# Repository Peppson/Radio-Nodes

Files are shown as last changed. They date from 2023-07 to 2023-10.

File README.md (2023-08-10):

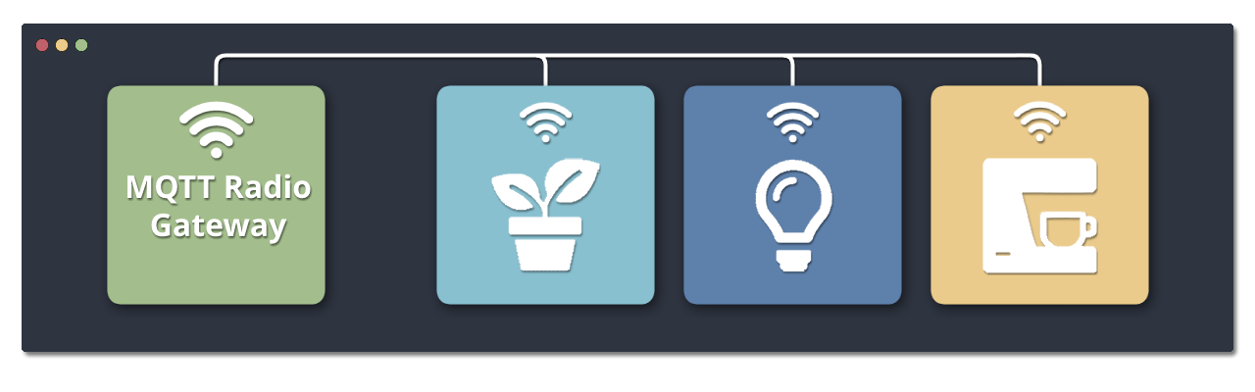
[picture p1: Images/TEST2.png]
flow diagram


# loading...

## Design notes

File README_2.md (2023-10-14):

flow_diagram

<div align="center">
    <h1>
        Radio Nodes         
        <a href="https://www.gnu.org/licenses/gpl-3.0"> 
            
        </a>     
    </h1>   
</div>

Solar/USB/Battery powered NRF24L01+ transceiver modules,  based on the Attiny84 microcontroller.  
Serves as the end-Node of [MQTT-Radio-Gateway](https://github.com/Peppson/MQTT-Radio-Gateway).     
Written in C++ with Arduino/PlatformIO framework.

&nbsp; 
## Project Overview
- Primarily made for personal "needs" and as a learning experience.   
  However if there's anything here that can benefit someone else's project,   
  feel free to use it!
- Easily configurable for different jobs, such as moving servos, starting pumps etc.
- Most configuration can be found in `include/config.h`.
- The `helpers` folder includes a few .ino files for calibration/setup etc.

&nbsp; 
## Hardware - PCB for Attiny84 MCU
Designed a custom PCB to fit all components more easily,  in a compact format.   
Kicad files can be found here: 
[📂 kicad - radio nodes/](./.kicad%20-%20ESP32%20shield)  
More project images in: 
[📂 images/](./images/)  

&nbsp;
Kicad PCB img   

### Finished hardware:
Finished hardware   

&nbsp; 
## Nodes

<details>
    <summary>
        Nodes 1-5: Solar-powered self watering plants
    </summary>

Uses a 3-5V waterpump and DIY capacative fluid-level sensor.  
[Liquid Level Sensing Using Capacitive-to-Digital Converters](https://www.analog.com/en/analog-dialogue/articles/liquid-level-sensing-using-cdcs.html)
<br>   
</details>

<details>
    <summary>
        Nodes 6-10: USB-powered self watering plants
    </summary>
    Same as above but skips the TP4056 charging board and battery.   

<br> 
</details>

<details>
    <summary>
        Node 11: Mocca Master controller 
    </summary>
    Uses a simple SG90 servo and a hall-effect current sensor.     
<br>
</details>

## License 
See the [LICENSE](./LICENSE) file for more information.  
&nbsp;

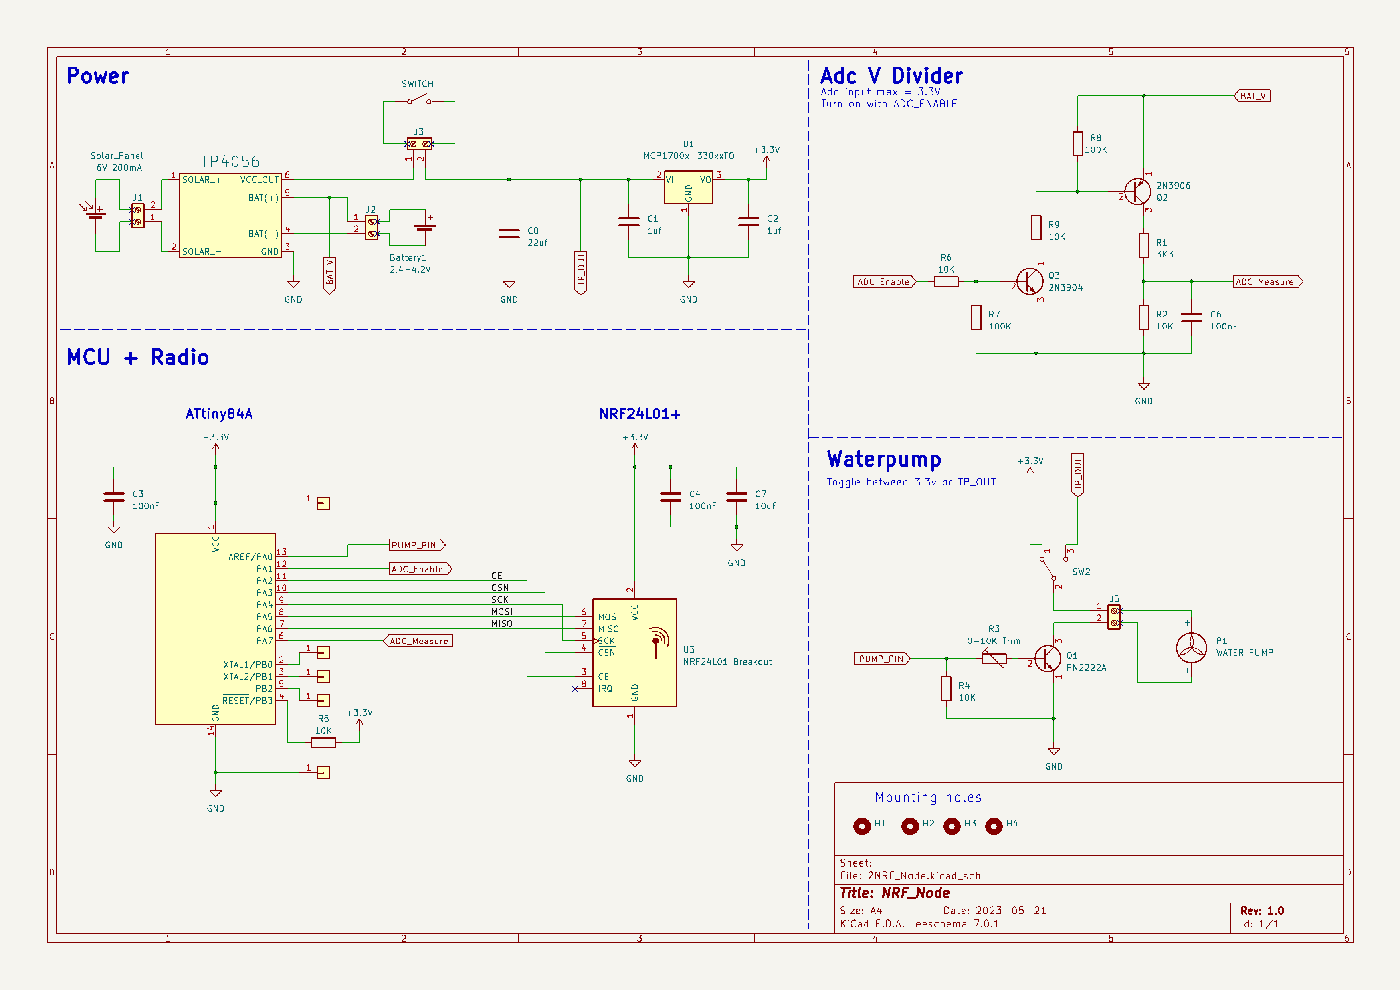
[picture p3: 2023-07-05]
Images/Kicad schematic.png

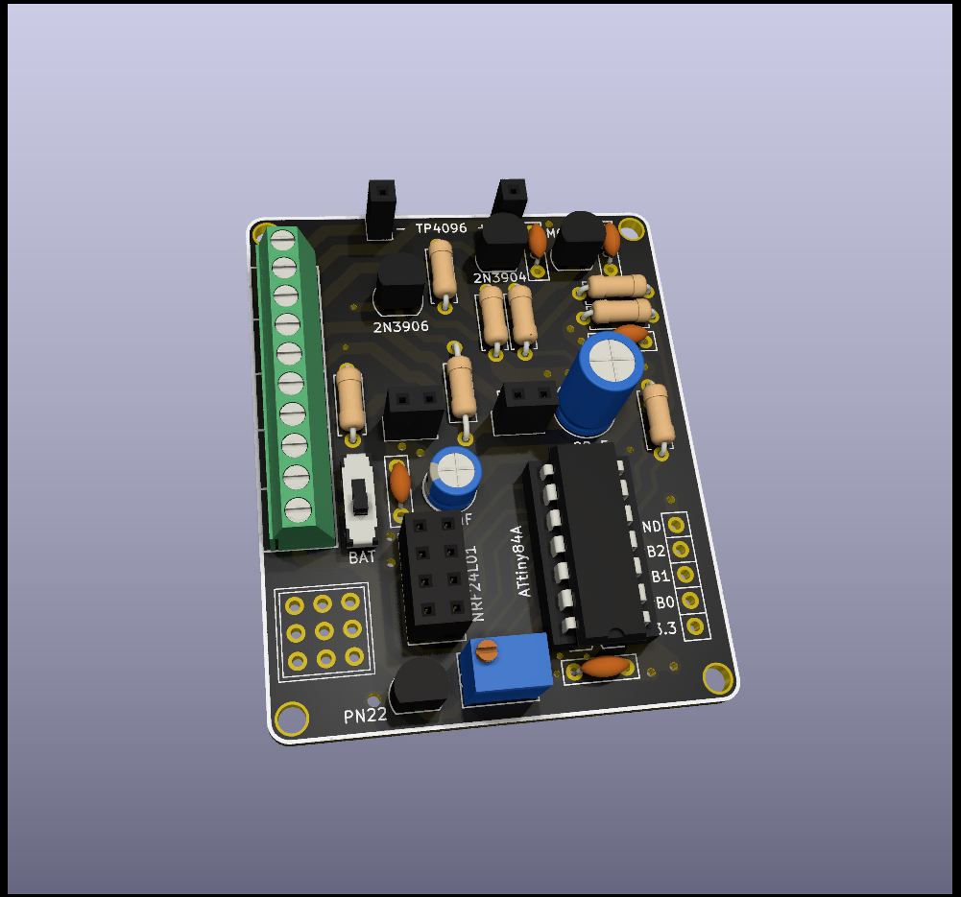
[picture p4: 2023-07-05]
Images/Node pcb.png

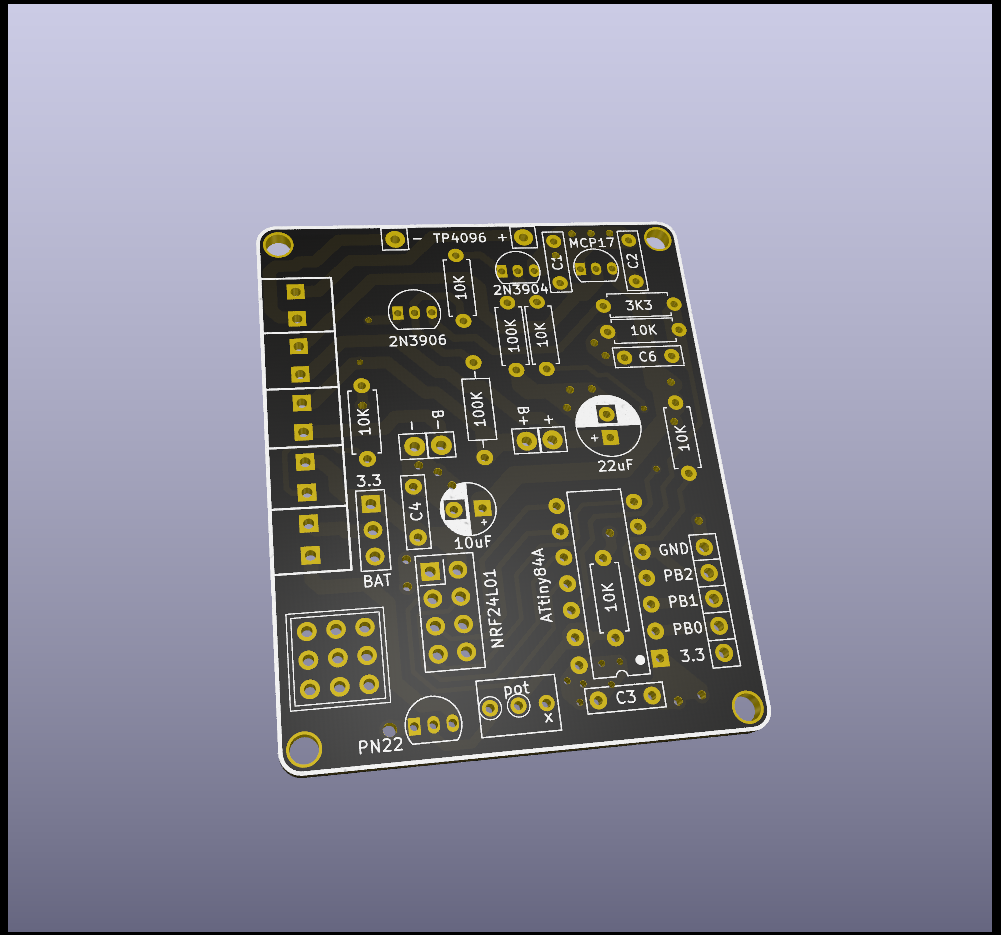
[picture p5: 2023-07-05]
Images/Node pcb naked.png

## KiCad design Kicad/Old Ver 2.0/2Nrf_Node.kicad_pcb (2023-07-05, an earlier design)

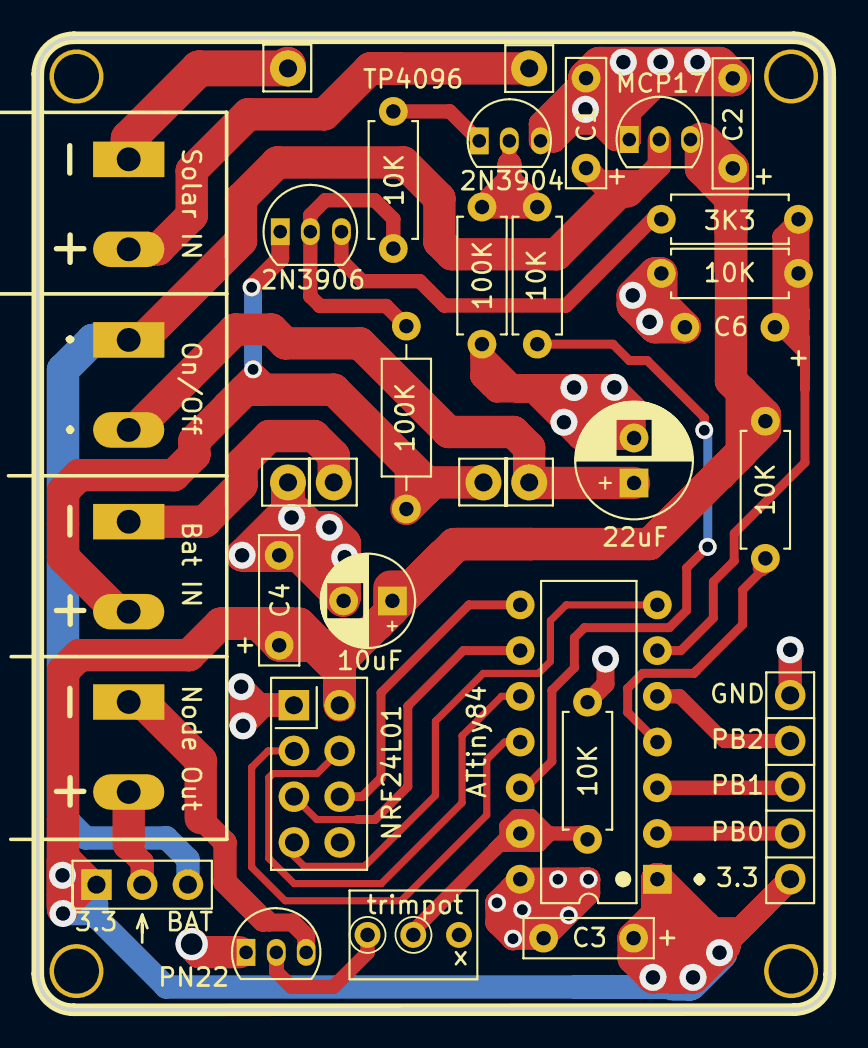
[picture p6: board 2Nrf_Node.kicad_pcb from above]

Board: 2 copper layers, 44.0 x 54.0 mm, 32 parts (0 on the bottom side), 26 nets.

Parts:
10K: 10K; R_Axial_DIN0207_L6.3mm_D2.5mm_P7.62mm_Horizontal
C1, C2: 1uf; C_Rect_L7.0mm_W2.0mm_P5.00mm
C3, C4, C6: 100nF; C_Rect_L7.0mm_W2.0mm_P5.00mm
C5: 22uF; CP_Radial_D6.3mm_P2.50mm
C7: 10uF; CP_Radial_D5.0mm_P2.50mm
H1, H2, H4, H4#2: MountingHole; TestPoint_Keystone_5010-5014_Multipurpose
J1, J2, J3, J4: Terminal Block; TerminalBlock_Altech_AK300-2_P5.00mm
Pins: PinHeader_1x03_P2.54mm_Vertical
Q1: PN2222A; TO-92_Inline
Q2: 2N3906; TO-92_Inline
Q3: 2N3904; TO-92_Inline
R1: 3K3; R_Axial_DIN0207_L6.3mm_D2.5mm_P7.62mm_Horizontal
R2, R3, R6, R9: 10K; R_Axial_DIN0207_L6.3mm_D2.5mm_P7.62mm_Horizontal
R7: 100K; R_Axial_DIN0207_L6.3mm_D2.5mm_P7.62mm_Horizontal
R8: 100K; R_Axial_DIN0207_L6.3mm_D2.5mm_P10.16mm_Horizontal
SW2: SW_SPDT; PinHeader_1x03_P2.54mm_Vertical
TP4056: TP4056-Module
U1: MCP1700x-330xxTO; TO-92_Inline
U2: ATtiny84A-P; DIP-14_W7.62mm
U3: NRF24L01_Breakout; nRF24L01_Breakout

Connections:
1234: Q3.1 (E), R9.2
+3.3V: 10K.2, C2.1, C3.1, C4.1, C7.1, Pins.5, SW2.1 (A), U1.3 (VO), U2.1 (VCC), U3.2 (VCC)
/CE: U2.11 (PA2), U3.3 (CE)
/CSN: U2.10 (PA3), U3.4 (~CSN)
/MISO: U2.7 (PA6), U3.7 (MISO)
/MOSI: U2.8 (PA5), U3.6 (MOSI)
/SCK: U2.9 (PA4), U3.5 (SCK)
ADC_Enable: R6.1, U2.12 (PA1)
ADC_Measure: C6.1, R1.2, R2.1, U2.6 (PA7)
BAT_-: J3.1, TP4056.6 (VCC_OUT)
BAT_V: Q2.1 (E), R8.1, TP4056.5 (BAT(+))
GND: C1.2, C2.2, C3.2, C4.2, C5.2, C6.2, C7.2, Pins.1, Q1.1 (E), Q3.3 (C), R2.2, R3.1, R7.2, TP4056.4 (BAT(-)), U1.1 (GND), U2.14 (GND), U3.1 (GND)
unnamed: J4.2, SW2.2 (B)
unnamed: J4.1, Q1.3 (C)
unnamed: Pins.2, U2.5 (PB2)
unnamed: Pins.4, U2.2 (XTAL1/PB0)
unnamed: Pins.3, U2.3 (XTAL2/PB1)
unnamed: R3.2, U2.13 (AREF/PA0)
unnamed: Q2.2 (B), R8.2, R9.1
unnamed: Q2.3 (C), R1.1
unnamed: Q3.2 (B), R6.2, R7.1
unnamed: 10K.1, U2.4 (~RESET/PB3)
tp_+: J1.2, TP4056.1 (VCC_IN)
tp_-: J1.1, TP4056.2 (GND)
tp_out_+: C5.1, J2.2, TP4056.3 (GND)
tp_out_++: C1.1, J2.1, SW2.3 (C), U1.2 (VI)

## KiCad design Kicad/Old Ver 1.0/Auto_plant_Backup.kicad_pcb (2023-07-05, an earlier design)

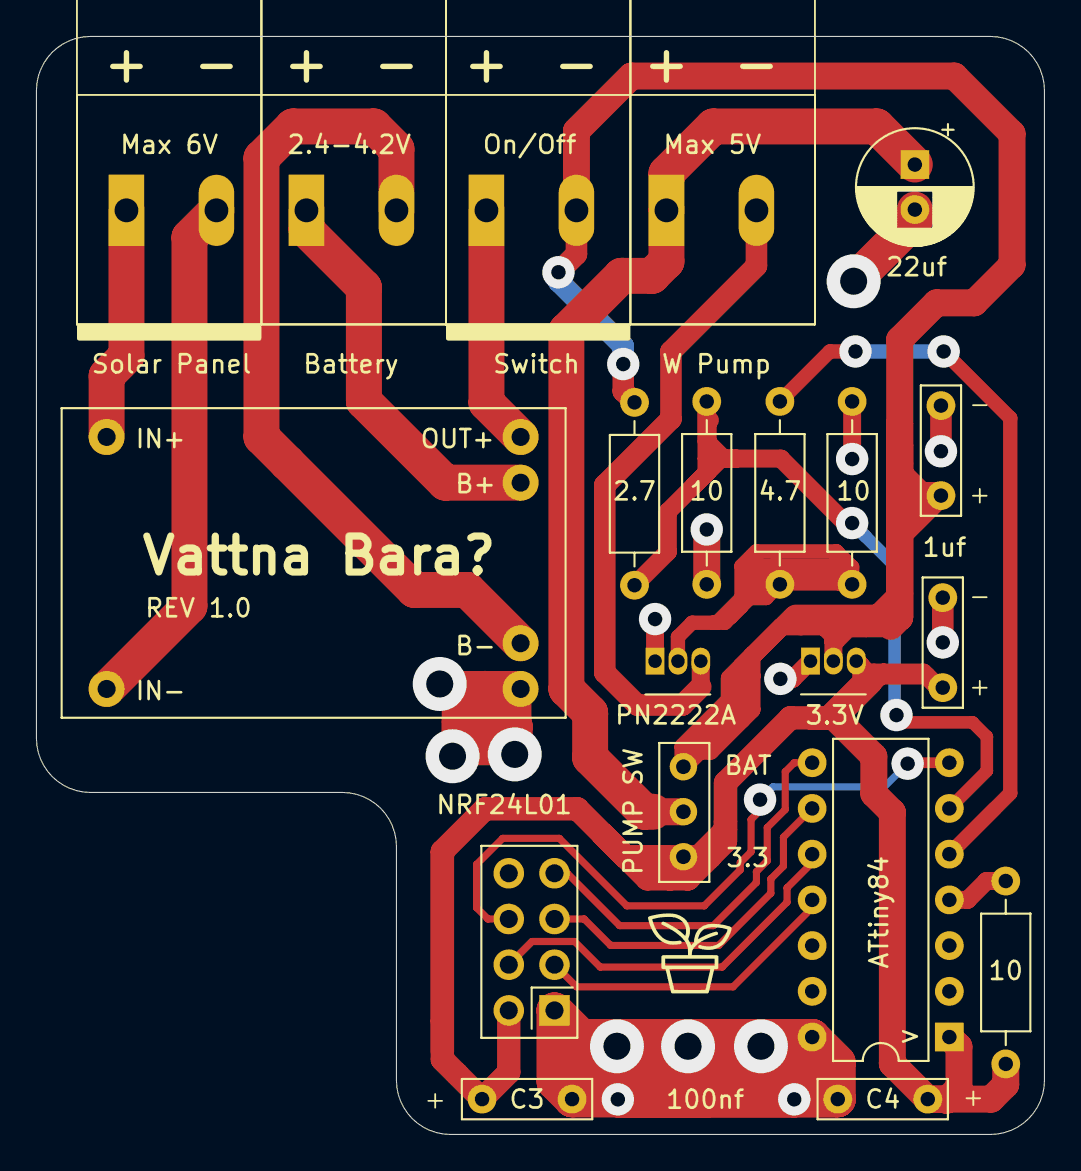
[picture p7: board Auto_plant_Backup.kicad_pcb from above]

Board: 2 copper layers, 56.0 x 61.0 mm, 20 parts (0 on the bottom side), 19 nets.

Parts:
2.7: 2.7k; R_Axial_DIN0207_L6.3mm_D2.5mm_P10.16mm_Horizontal
3.3V: MCP1700x-330xxTO; TO-92_Inline
4.7, 10#3: 4.7k; R_Axial_DIN0207_L6.3mm_D2.5mm_P10.16mm_Horizontal
10, 10#2: 10k; R_Axial_DIN0207_L6.3mm_D2.5mm_P10.16mm_Horizontal
22uf: CP_Radial_D6.3mm_P2.50mm
100nf: 100nf; C_Rect_L7.0mm_W2.0mm_P5.00mm
+: Switch; TerminalBlock_Altech_AK300-2_P5.00mm
+#2: W Pump; TerminalBlock_Altech_AK300-2_P5.00mm
+#3: Battery; TerminalBlock_Altech_AK300-2_P5.00mm
-: Solar Panel; TerminalBlock_Altech_AK300-2_P5.00mm
ATtiny84: DIP-14_W7.62mm
C1, C2: 1uf; C_Rect_L7.0mm_W2.0mm_P5.00mm
C4: 100nf; C_Rect_L7.0mm_W2.0mm_P5.00mm
NRF24L01: NRF24L01_Breakout; nRF24L01_Breakout
PN2222A: PN2222A; TO-92_Inline
SW2: SW_SPDT; 2_way_switch
TP4056: TP4056-Module

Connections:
+3.3V: 3.3V.3 (VO), 10#3.2, 100nf.1, ATtiny84.1, C2.1, C4.1, NRF24L01.2 (VCC), SW2.1 (A)
/CE: ATtiny84.11, NRF24L01.3 (CE)
/MISO: ATtiny84.8, NRF24L01.7 (MISO)
/MOSI: ATtiny84.7, NRF24L01.6 (MOSI)
/SCK: ATtiny84.9, NRF24L01.5 (SCK)
BAT_V: 2.7.1, 3.3V.2 (VI), +.2, C1.1, SW2.3 (C)
CSN: ATtiny84.10, NRF24L01.4 (~CSN)
GND: 3.3V.1 (GND), 10.2, 10#2.2, 22uf.2, 100nf.2, ATtiny84.14, C1.2, C2.2, C4.2, NRF24L01.1 (GND), PN2222A.1 (E), TP4056.4 (BAT(-))
unnamed: -.2, TP4056.2 (GND)
unnamed: -.1, TP4056.1 (VCC_IN)
unnamed: +#3.2, TP4056.6 (VCC_OUT)
unnamed: +#3.1, TP4056.5 (BAT(+))
unnamed: +.1, TP4056.3 (GND)
unnamed: +#2.2, PN2222A.3 (C)
unnamed: 4.7.2, 10#2.1, PN2222A.2 (B)
unnamed: 4.7.1, ATtiny84.5
PA1: 2.7.2, 10.1, ATtiny84.6
P_OUT: 22uf.1, +#2.1, SW2.2 (B)
RESET: 10#3.1, ATtiny84.RESET

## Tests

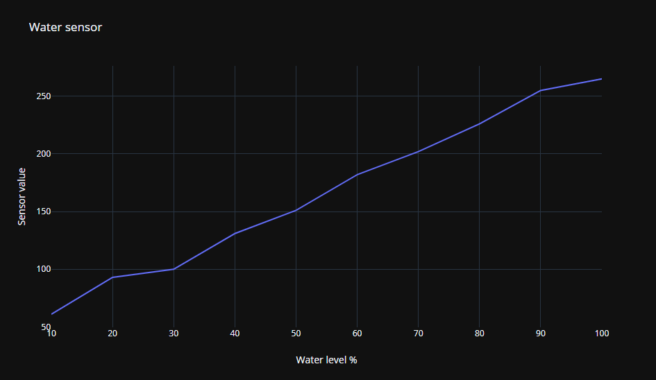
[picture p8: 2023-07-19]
Images/Node 1 water_sensor_calibration.PNG

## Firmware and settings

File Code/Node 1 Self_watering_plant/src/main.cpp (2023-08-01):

/*
##########################  Radio Node 1  ##########################
#                                                                  #
#   - Self watering flowerpot, controlled via MQTT Radio gateway   #                                          
#   - NRF24L01+ Radio Address "1"                                  #     
#   - Target Mcu = ATtiny84A @ 4Mhz                                #
#                                                                  #
####################################################################
*/


// main.cpp
#include "config.h"
#include "program.h"
class RF24Radio radio_24;
class HardwareClass hardware;
class CapacitorLite water_sensor(WATER_SENSOR_PIN_1, WATER_SENSOR_PIN_2);
 

// Setup
void setup() { 
    hardware.setup();
    #if ADC_CAL_ENABLED
        extern void adc_calibration(); 
        adc_calibration();
    #elif PUMP_CAL_ENABLED
        extern void pump_calibration();
        pump_calibration();
    #else
        radio_24.send_data_get_time();
        hardware.send_data_timestamp = millis() + UPDATE_INTERVAL;
    #endif  
}


// Main loop
void loop() {
    // Save power, toggle radio transciever on/off
    for (uint8_t i = 0; i < LOOP_ITERATIONS; i++) {
        uint16_t rf24_package[6] = {};

        // Powerup radio, reset watchdog
        WDT_RESET();
        radio_24.powerUp();
        delay(5);
        radio_24.startListening();

        // Listen for incomming message
        if (radio_24.wait_for_message(200, rf24_package)) {
            hardware.water_pump_control(rf24_package);
        }
        // Powerdown radio 
        radio_24.stopListening();
        if (i < LOOP_ITERATIONS) {
            radio_24.powerDown();
            delay(RF24_SLEEP_TIME);
        }     
    } 
    // Memory related #if... 
    #if !ADC_CAL_ENABLED 
        uint32_t current_timestamp = millis();
        
        // Time for deepsleep?
        if (current_timestamp > hardware.sleep_at_this_timestamp) {
            DEEPSLEEP(); 

        // Send node data to master every UPDATE_INTERVAL
        } else if (current_timestamp > hardware.send_data_timestamp) {
            hardware.send_data_timestamp = millis() + UPDATE_INTERVAL; 
            radio_24.send_data_get_time();   
        }
    #endif  
}

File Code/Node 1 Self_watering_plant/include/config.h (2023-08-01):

// config.h
#pragma once
#include <Arduino.h>
#include <stdint.h>
#include <SPI.h>
#include <RF24.h>  
#include "nRF24L01.h"  
#include <capacitor_lite.h> 


// User Controlled
#define ATTINY84_ENABLED 1                      // ATtiny84 or other MCUs
#define WATCHDOG_ENABLED 1                      // Enable watchdog     
#define SERIAL_ENABLED 0                        // Serial toggle
#define ADC_CAL_ENABLED 0                       // Enter battery ADC calibration (Req SERIAL_ENABLED)
#define PUMP_CAL_ENABLED 0                      // Enter pump ADC calibration (Req SERIAL_ENABLED)

#define RF24_THIS_DEV_ADDRESS 1                 // This device address
#define RF24_THIS_DEV_ADDRESS_STRING "1Adrs"    // Address string "1Adrs", "2Adrs", "10Adr", "11Adr"...
#define RF24_SLEEP_TIME 800                     // 200ms on, (ms) off                                   
#define RF24_CHANNEL 120                        // Channel 1-126 (RF_Scanner.ino)
#define RF24_OUTPUT (RF24_PA_MAX)               // Output level: RF24_PA_MIN, RF24_PA_LOW, RF24_PA_HIGH, RF24_PA_MAX
#define RF24_DATARATE (RF24_250KBPS)            // Datarate: RF24_2MBPS, RF24_1MBPS, RF24_250KBPS
#define RF24_PIPE 1                             // Pipe address (CONST)
#define RF24_MASTER_NODE_ADDRESS 0              // Address of master (CONST)

#define PUMP_RUNTIME_MAX 6                      // Maximum time pump is allowed to run (s)  
#define WATER_SENSOR_MIN_VALUE 70               // Calibrated with EMPTY tank, diy sensor mostly linear
#define WATER_SENSOR_MAX_VALUE 265              // Calibrated with FULL tank, diy sensor mostly linear

#define DEEPSLEEP_AT_THIS_TIME 2100             // Go to deepsleep at what time? (hhmm)
#define DEEPSLEEP_HOW_MANY_HOURS 12             // Deepsleep how long in (h)
#define UPDATE_INTERVAL 3*60*60*1000UL          // How often should the node send status update to master? (h*m*s*ms)
#define LOOP_ITERATIONS 20                      // Main loop iterations (max uint8_t)


// Global counter while in deepsleep
extern volatile int deepsleep_counter;


// Board Select
#if ATTINY84_ENABLED 
    #include <ATTinyCore.h>
    #include <avr/wdt.h>
    #include <avr/sleep.h>
    #define CE_PIN A2         
    #define CSN_PIN A3
    #define ADC_MEASURE_PIN A7
    #define ADC_ENABLE_PIN PB1      // Ver 4.0 = PB1
    #define PUMP_PIN A0             // Ver 4.0 = A0
    #define WATER_SENSOR_PIN_1 PB2 
    #define WATER_SENSOR_PIN_2 PA1
    #define SERIAL_OUT_PIN PB0
    #define WDT_RESET() wdt_reset() 
    #define WDT_DISABLE() wdt_disable()
    #define WDT_ENABLE(x) wdt_enable(x)
    #define DEEPSLEEP(x) hardware.deepsleep(x);
#else
    #define CE_PIN 14       // Pico 14, pico zero 0, esp32 14
    #define CSN_PIN 5       // Pico 17, pico zero 1, esp32 5
    #define ADC_MEASURE_PIN 25
    #define ADC_ENABLE_PIN 26
    #define PUMP_PIN 2
    #define WATER_SENSOR_PIN_1 //PIN
    #define WATER_SENSOR_PIN_2 //PIN
    #define WDT_RESET()
    #define WDT_DISABLE()
    #define WDT_ENABLE(x)
    #define DEEPSLEEP(x)
#endif


// Serial toggle
#if SERIAL_ENABLED && ATTINY84_ENABLED
    #include <SendOnlySoftwareSerial.h>
    extern SendOnlySoftwareSerial tiny_serial;
    #define SERIAL_BEGIN(x) tiny_serial.begin(x)
    #define print(x) tiny_serial.print(x)
    #define println(x) tiny_serial.println(x)
    #define debug_print(x)
    #define debug_println(x)

#elif SERIAL_ENABLED && !ATTINY84_ENABLED
    #define SERIAL_BEGIN(x) Serial.begin(x)
    #define print(x) Serial.print(x)
    #define println(x) Serial.println(x)
    #define debug_print(x) print(x)
    #define debug_println(x) println(x)

#else // Cast print statements into nothing
    #define SERIAL_BEGIN(x)
    #define print(x)
    #define println(x)
    #define debug_print(x)
    #define debug_println(x)
#endif

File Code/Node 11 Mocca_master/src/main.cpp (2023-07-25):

/*
#########################  Radio Node 11  #########################
#                                                                 #
#  - Mocca Master Controller, controlled via MQTT Radio gateway   #                                          
#  - NRF24L01+ Radio Address "11"                                 #     
#  - Target Mcu = ATtiny84A @ 4Mhz                                #
#                                                                 #
###################################################################
*/


// Main.cpp
#include "config.h"
#include "program.h"
class RF24Radio radio_24;
class HardwareClass hardware;


// Setup
void setup() { 
    hardware.setup();
    #if ADC_CAL_ENABLED
        extern void adc_calibration(); 
        adc_calibration();
    #else
        hardware.coffee_count = hardware.read_value_from_EEPROM();
        hardware.coffee_state = hardware.get_mocca_master_state();
        hardware.move_servo(0, true);
        radio_24.send_data_get_time();
    #endif  
}


// Main loop
void loop() {
    // Save power, toggle radio transciever on/off
    for (uint8_t i = 0; i < LOOP_ITERATIONS; i++) {
        uint16_t rf24_package[6] = {};
        uint32_t current_timestamp = millis();

        // Powerup radio, reset watchdog
        WDT_RESET();
        radio_24.powerUp();
        delay(5);
        radio_24.startListening();

        // Listen for incomming message
        if (radio_24.wait_for_message(200, rf24_package)) {
            hardware.mocca_master_control(rf24_package);
        }
        // Periodically check Mocca master state
        if (current_timestamp > hardware.prevoius_timestamp + 1500) {  
            hardware.prevoius_timestamp = millis();

            // Have coffee_state changed seens last check?
            bool new_coffee_state = hardware.get_mocca_master_state();
            if (new_coffee_state != hardware.coffee_state) {

                // Increment coffee_count only if turned on (from off to on)
                if (new_coffee_state && !hardware.coffee_state) { 
                    hardware.coffee_count += 1;
                    hardware.update_value_to_EEPROM();
                }
                // Update coffee_state and send status update to master
                hardware.coffee_state = new_coffee_state;
                radio_24.try_send_message();
            }
        }
        // Powerdown radio and "sleep" (blocking)
        radio_24.stopListening();
        radio_24.powerDown();
        delay(RF24_SLEEP_TIME);   
    }
    // Time for deepsleep?
    if (millis() > hardware.sleep_at_this_timestamp) { DEEPSLEEP(); } 
}

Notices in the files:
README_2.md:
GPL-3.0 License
